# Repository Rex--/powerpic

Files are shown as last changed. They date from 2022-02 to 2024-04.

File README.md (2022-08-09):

# PowerPIC Calculator Watch
The PowerPIC is a replacement board for Casio CA-53W Databank watches with
upgraded hardware and customizable firmware. The project was designed with
the intent for a personal watch, but all of the needed design files and
firmware is available for free so anyone can make their own (if you can get
the PICs!).

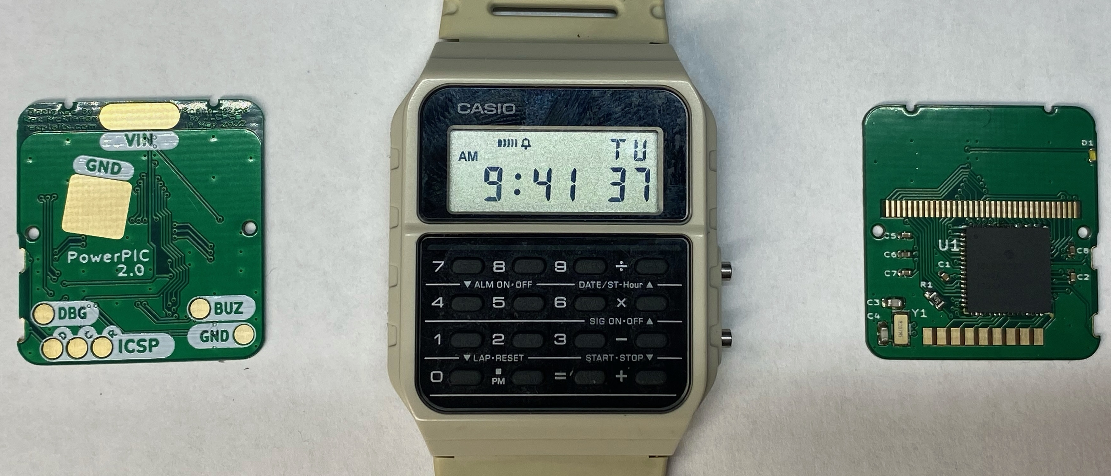
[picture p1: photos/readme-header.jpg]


## Features
- Full control of all 82 segments on the original display.
- Interrupt enabled keypad and buttons.
- Variable frequency piezo buzzer.
- Single color LED backlight.
- Built in temperature sensor.
- 12-bit ADC for sensing battery charge.

## Documentation
**Firmware:** The current state of the firmware is heavily evolving, so
the best source of documentation is the code itself, located in the `firmware/`
directory. A Doxyfile is provided, however the generated documentation should
be considered incorrect and outdated.

**Hardware:** Design files and schematics are available in the `hardware/`
directory.

## Credits
Thanks to Travis and Joey, I obtained a lot of inspiration from their projects:
- [GoodWatch](https://github.com/travisgoodspeed/goodwatch) --
Another CA-53W replacement board based on TI's MSP430.
- [Sensor Watch](https://github.com/joeycastillo/Sensor-Watch) --
A replacement board for the classic Casio F-91W based on Microchip's ATSAML22.

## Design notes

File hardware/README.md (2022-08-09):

# PowerPIC Hardware

The PowerPIC is built on a PIC16LF19197 with 56KB of flash memory and 4KB of RAM.
Required features included: a real time clock and calendar module for timekeeping,
a LCD controller for driving the stock Casio display, and a 10-bit PWM for driving
the piezo buzzer. Some additional useful features are: a 12-bit ADC for roughly
determining battery level, and a temperature sensor for roughly gauging temperature.

The only other components besides the required passives are a 32.768kHz crystal,
and a LED that is used for the backlight.

## Changelog

**Version 2.0**
- Added experimental backlight.
- Added RTC crystal for accurate timekeeping.

**Version 1.1**
- Switched buzzer from RF0 to RG7 so we can use the PWM peripheral.
- Switched keypad rows to RA0-RA3. Row 1 was using RA5 which is VBAT and unusable as digital output
- Added additional test points for the side buttons, allowing buttons to be simulated for development
- Added additional GND test point

**Version 1.0**
 - First hardware version

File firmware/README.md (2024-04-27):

# CasiOS
The watch firmware is written in C and compiled with Microchip's `xc8` compiler.
Functionality is separated into 'mode' applications, with each mode implementing
a set of procedures to be run when active. The active mode is changed by the Mode
side button, with each press cycling through an array of modes.

## Requirements
The following programs are required to build and flash the firmware:
- `make`
- `xc8` - Microchip's C compiler for PICx Devices
- `picchick` - Flash PICs using an AVR device. Get it 
[from the repo](https://github.com/rex--/picchick).

## Configuration

### Build Options
These options modify things about the firmware at build time and can be found
in the Makefile:
- `MODES` - A list of modes to compile into the firmware.
- `PCB_REV` - PCB Major version number. Changes some pins and which clock to use.
- `LOG_LVL` - Sets the amount of logged information. Logs above the specified
    level are not compiled into the final firmware, so expect things to run
    differently. A log level of '0' is recommend for builds that are going into a
    watch for use.
- `XTAL_FREQ` - The frequency in Hertz of the oscillator. Changing this value
    _DOES_ change the frequency of the internal oscillator!
- `BOOT_OFFSET` - Offset for bootloader. Set to 0 if not using a bootloader.

### Library Config
Some libraries have their own configuration options. These can be found in
the corresponding header files in `src/lib/`:
- **logging.h**
  - `LOGGING_UART_BAUDRATE` - The baud rate of the debug UART connection.

### Programmer Config
Configure the serial device to use in the Makefile. This should be a
1-wire capable serial converter.
- `PROGRAMMER_PORT` - Serial port of picchick compatible programmer. 
    e.g. _/dev/ttyUSB0_ or _COM3_
- `PROGRAMMER_BAUD` - Baud rate of programmer serial connection.
- `PROGRAMMER_FLAGS` - Additional programmer flags to use.

### Configuring Modes
To configre which modes are built into the firmware, edit the `modes.cfg`
file located in `src/modes/`. Each mode's source files, header files, and
mode_app_t struct should have the same name which corresponds to the name used
in the config file.

## Building
Compilation is achieved with the _make_ utility. A run of the `make fw` command
will produce a CasiOS.hex file in the sub-directory `build/`. The command
`make clean` will delete all built files, and a `make fclean` will remove all
files and created directories.
```sh
make [fw]       # Build firmware with settings defined in Makefile
make clean      # Remove built firmware files
make fclean     # Remove all created files and folders
```

The header file `src/modes/mode_config.h` is automatically generated with the
`make config` command. The generated files can be removed with `make cclean`.
Note that the config is generated automatically with `make fw` and removed with
a `make fclean`.
```sh
make config     # Generate config files
make cclean     # Remove generated files
```

## Upload
Python utility `picchick` is used by the Makefile in conjuction with
**flipflop** to upload firmware. It requires a serial device connected to
the PowerPIC's Debug and Ground pins. For further information about uploading
firmware checkout [flipflop](https://github.com/Rex--/flipflop), the bootloader
used for the PowerPIC.

After configuring the serial device in the Makefile, `make upload` should
upload the firmware to the watch. Don't forget to enter the bootloader by
resetting the watch!

```sh
make upload      # Upload firmware using picchick
```

## Copying
Copyright © 2022-2024 Rex McKinnon \
This software is released under the University of Illinois/NCSA Open Source
License. Check the LICENSE file for more details.

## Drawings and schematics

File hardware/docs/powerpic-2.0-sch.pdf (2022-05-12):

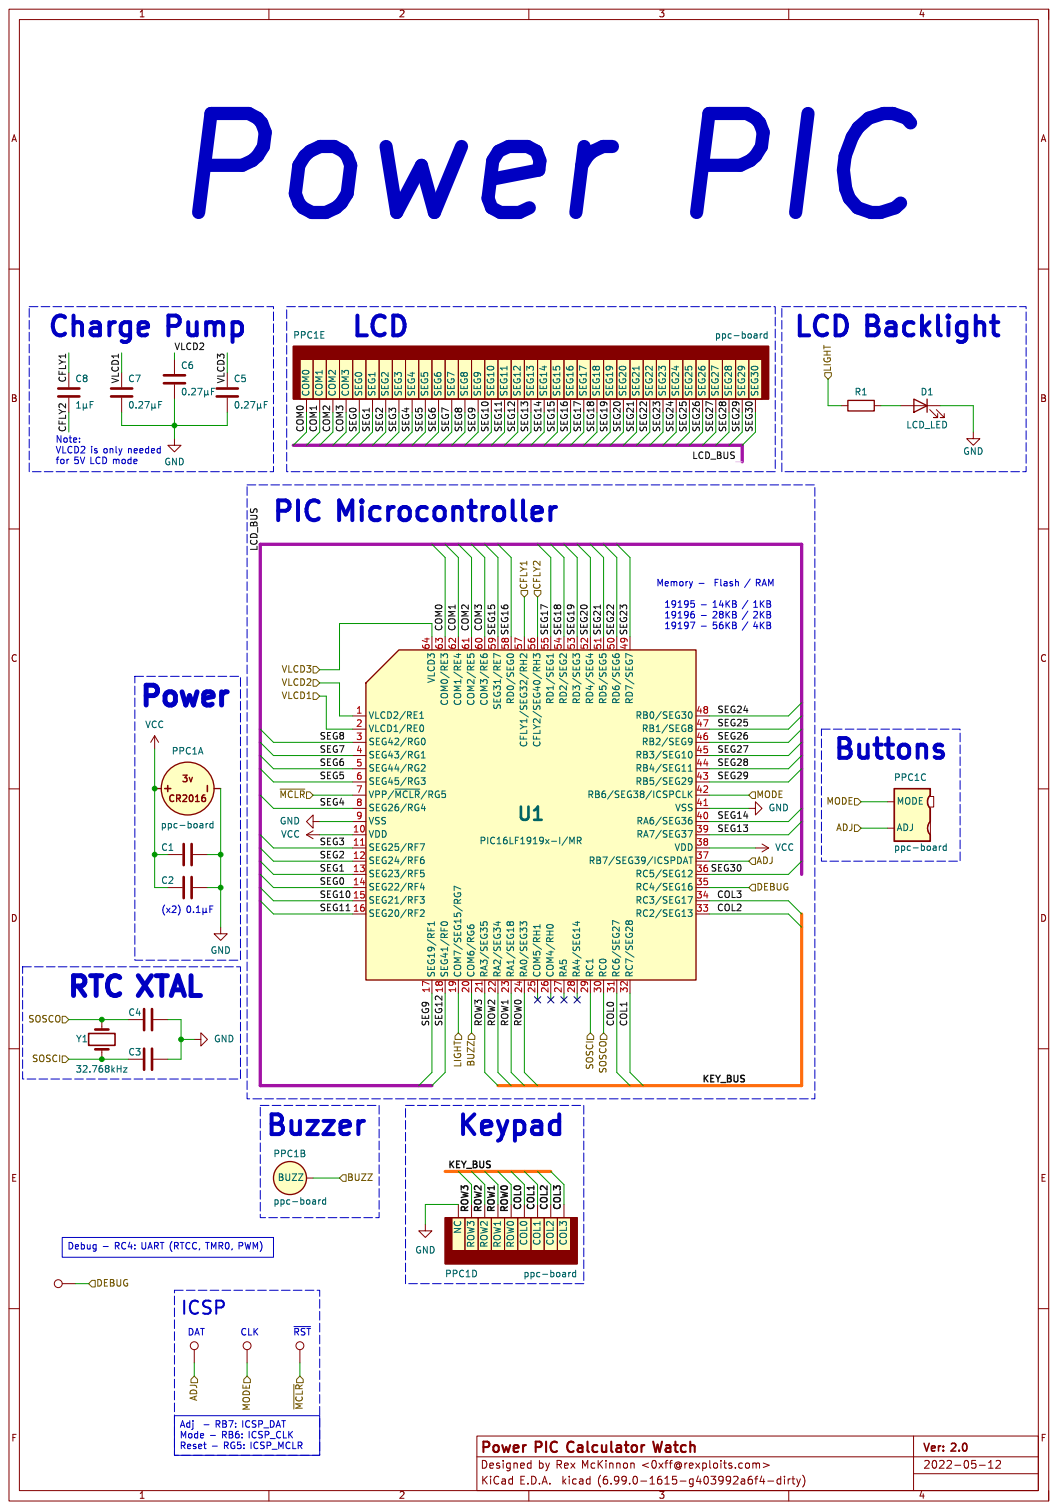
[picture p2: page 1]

for 5V LCD mode Charge Pump

Note: VLCD2 is only needed

Debug - RC4: UART (RTCC, TMR0, PWM)

2022-05-12 Power PIC Calculator Watch

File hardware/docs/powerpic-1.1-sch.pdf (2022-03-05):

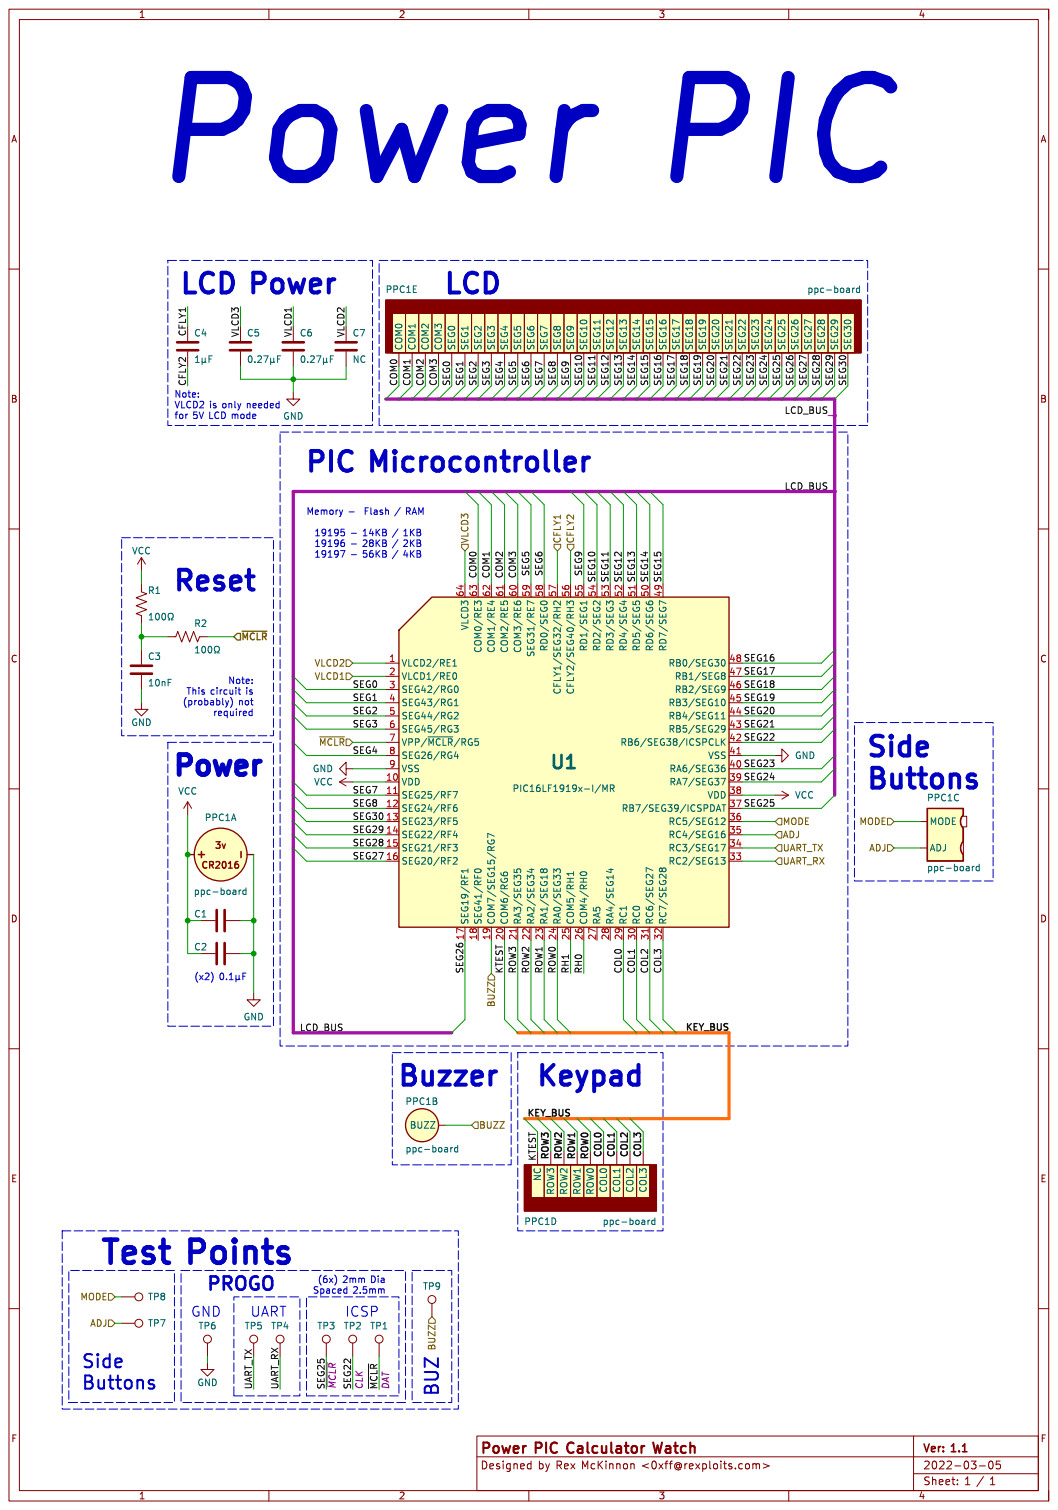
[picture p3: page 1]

Note: VLCD2 is only needed

Note: This circuit is

2022-03-05 Sheet: 1 / 1 Power PIC Calculator Watch
Designed by Rex McKinnon <0xff@rexploits.com>

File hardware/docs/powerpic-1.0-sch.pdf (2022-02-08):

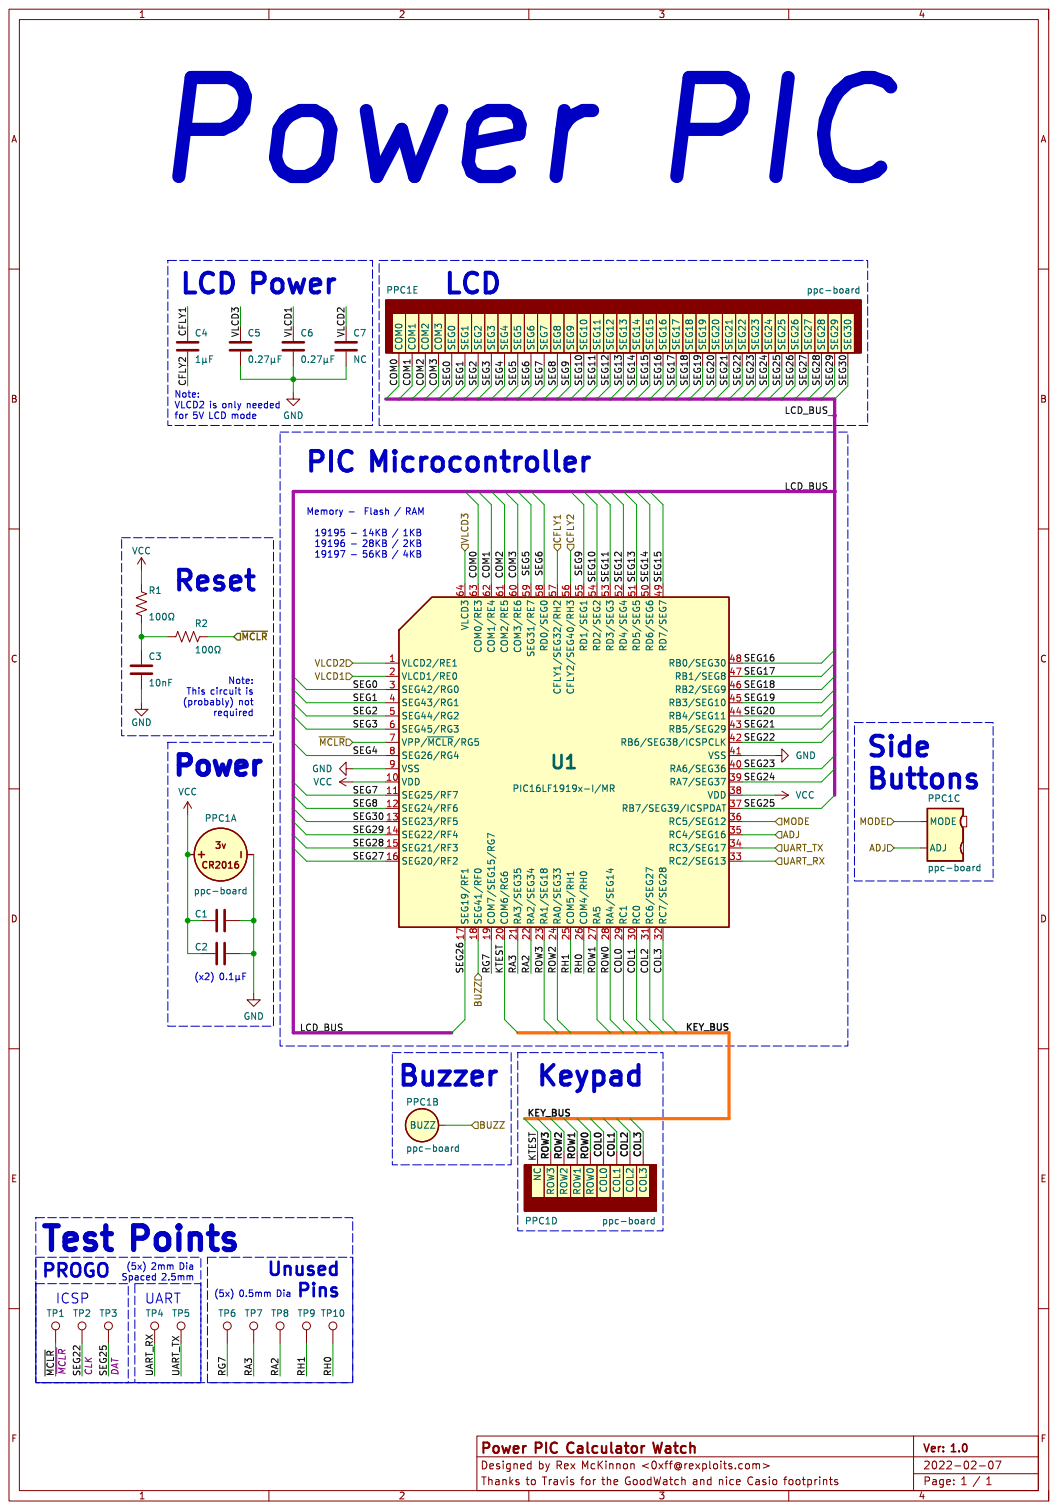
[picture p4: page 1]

for 5V LCD mode LCD Power

Note: VLCD2 is only needed

Note: This circuit is

Power PIC Calculator Watch
Designed by Rex McKinnon <0xff@rexploits.com>

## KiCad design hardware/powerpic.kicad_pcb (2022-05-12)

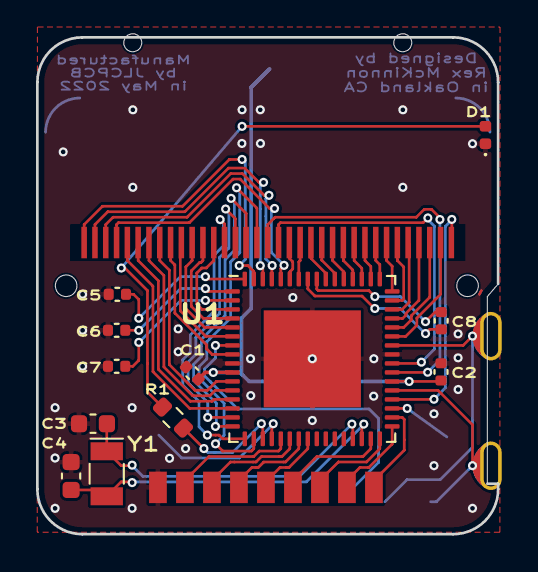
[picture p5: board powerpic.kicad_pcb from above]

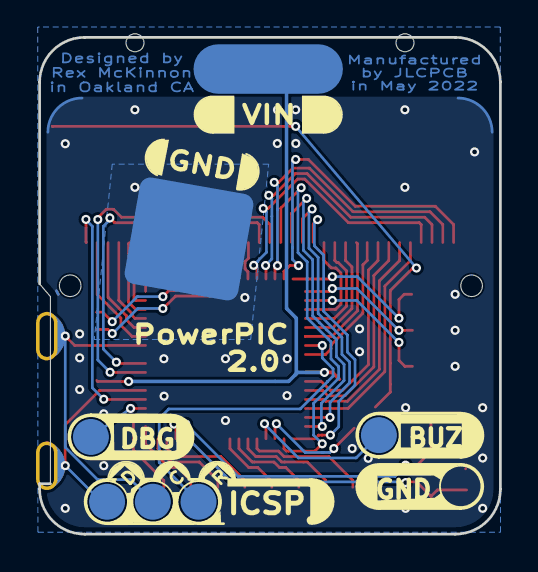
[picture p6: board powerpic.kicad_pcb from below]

Board: 2 copper layers, 25.6 x 27.6 mm, 17 parts (4 on the bottom side), 59 nets.

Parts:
C1, C2: 0.1μF; C_0402_1005Metric
C3, C4: TBD; C_0603_1608Metric
C5, C6, C7: 0.27μF; C_0402_1005Metric
C8: 1μF; C_0402_1005Metric
D1: LCD_LED; LED_0402_1005Metric
PPC1: ppc-board
R1: TBD; R_0603_1608Metric
TP1: ~{MCLR}; Progo_Pad_D2.0mm
TP2: Mode; Progo_Pad_D2.0mm
TP3: Adj; Progo_Pad_D2.0mm
TP4: Debug; Progo_Pad_D2.0mm
U1: PIC16LF1919x-I/MR; QFN-64-1EP_9x9mm_P0.5mm_EP5.4x5.4mm
Y1: 32.768kHz; Crystal_SMD_MicroCrystal_CC7V-T1A-2Pin_3.2x1.5mm

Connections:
/ADJ: PPC1.5 (ADJ), TP3.1, U1.37 (RB7/SEG39/ICSPDAT)
/BUZZ: PPC1.3 (BUZZ), U1.20 (COM6/RG6)
/CFLY1: C8.1, U1.57 (CFLY1/SEG32/RH2)
/CFLY2: C8.2, U1.56 (CFLY2/SEG40/RH3)
/COL0: PPC1.11 (COL0), U1.31 (RC6/SEG27)
/COL1: PPC1.12 (COL1), U1.32 (RC7/SEG28)
/COL2: PPC1.13 (COL2), U1.33 (RC2/SEG13)
/COL3: PPC1.14 (COL3), U1.34 (RC3/SEG17)
/COM0: PPC1.15 (COM0), U1.63 (COM0/RE3)
/COM1: PPC1.16 (COM1), U1.62 (COM1/RE4)
/COM2: PPC1.17 (COM2), U1.61 (COM2/RE5)
/COM3: PPC1.18 (COM3), U1.60 (COM3/RE6)
/DEBUG: TP4.1, U1.35 (RC4/SEG16)
/LIGHT: R1.2, U1.19 (COM7/SEG15/RG7)
/MODE: PPC1.4 (MODE), TP2.1, U1.42 (RB6/SEG38/ICSPCLK)
/ROW0: PPC1.10 (ROW0), U1.24 (RA0/SEG33)
/ROW1: PPC1.9 (ROW1), U1.23 (RA1/SEG18)
/ROW2: PPC1.8 (ROW2), U1.22 (RA2/SEG34)
/ROW3: PPC1.7 (ROW3), U1.21 (RA3/SEG35)
/SEG0: PPC1.19 (SEG0), U1.14 (SEG22/RF4)
/SEG1: PPC1.20 (SEG1), U1.13 (SEG23/RF5)
/SEG2: PPC1.21 (SEG2), U1.12 (SEG24/RF6)
/SEG3: PPC1.22 (SEG3), U1.11 (SEG25/RF7)
/SEG4: PPC1.23 (SEG4), U1.8 (SEG26/RG4)
/SEG5: PPC1.24 (SEG5), U1.6 (SEG45/RG3)
/SEG6: PPC1.25 (SEG6), U1.5 (SEG44/RG2)
/SEG7: PPC1.26 (SEG7), U1.4 (SEG43/RG1)
/SEG8: PPC1.27 (SEG8), U1.3 (SEG42/RG0)
/SEG9: PPC1.28 (SEG9), U1.17 (SEG19/RF1)
/SEG10: PPC1.29 (SEG10), U1.15 (SEG21/RF3)
/SEG11: PPC1.30 (SEG11), U1.16 (SEG20/RF2)
/SEG12: PPC1.31 (SEG12), U1.18 (SEG41/RF0)
/SEG13: PPC1.32 (SEG13), U1.39 (RA7/SEG37)
/SEG14: PPC1.33 (SEG14), U1.40 (RA6/SEG36)
/SEG15: PPC1.34 (SEG15), U1.59 (SEG31/RE7)
/SEG16: PPC1.35 (SEG16), U1.58 (RD0/SEG0)
/SEG17: PPC1.36 (SEG17), U1.55 (RD1/SEG1)
/SEG18: PPC1.37 (SEG18), U1.54 (RD2/SEG2)
/SEG19: PPC1.38 (SEG19), U1.53 (RD3/SEG3)
/SEG20: PPC1.39 (SEG20), U1.52 (RD4/SEG4)
/SEG21: PPC1.40 (SEG21), U1.51 (RD5/SEG5)
/SEG22: PPC1.41 (SEG22), U1.50 (RD6/SEG6)
/SEG23: PPC1.42 (SEG23), U1.49 (RD7/SEG7)
/SEG24: PPC1.43 (SEG24), U1.48 (RB0/SEG30)
/SEG25: PPC1.44 (SEG25), U1.47 (RB1/SEG8)
/SEG26: PPC1.45 (SEG26), U1.46 (RB2/SEG9)
/SEG27: PPC1.46 (SEG27), U1.45 (RB3/SEG10)
/SEG28: PPC1.47 (SEG28), U1.44 (RB4/SEG11)
/SEG29: PPC1.48 (SEG29), U1.43 (RB5/SEG29)
/SEG30: PPC1.49 (SEG30), U1.36 (RC5/SEG12)
/SOSCI: C3.1, U1.29 (RC1), Y1.1
/SOSCO: C4.1, U1.30 (RC0), Y1.2
/VLCD1: C7.1, U1.2 (VLCD1/RE0)
/VLCD2: C6.1, U1.1 (VLCD2/RE1)
/VLCD3: C5.1, U1.64 (VLCD3)
/~MCLR: TP1.1, U1.7 (VPP/~MCLR/RG5)
GND: C1.1, C2.1, C3.2, C4.2, C5.2, C6.2, C7.2, D1.1 (K), PPC1.2 (GND), PPC1.6 (NC), U1.9 (VSS), U1.41 (VSS), U1.65 (VSS)
unnamed: D1.2 (A), R1.1
VCC: C1.2, C2.2, PPC1.1 (VCC), U1.10 (VDD), U1.38 (VDD)

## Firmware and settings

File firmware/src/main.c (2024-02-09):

/** @file main.c
 *
 * Main program for the PowerPIC firmware.
 *
 * TODO: Write a nice description about the PowerPIC firmware.
 * 
*/

#include <xc.h>

#include "post.h"

#include "lib/system.h"
#include "lib/isr.h"
#include "lib/mode.h"
#include "lib/events.h"
#include "lib/tick.h"
#include "lib/datetime.h"
#include "lib/alarm.h"
#include "lib/buttons.h"
#include "lib/keypad.h"
#include "lib/backlight.h"
#include "lib/buzzer.h"
#include "lib/display.h"
#include "lib/battery.h"

#define LOG_TAG "main"
#include "lib/logging.h"


/**
 * Setup of hardware and libs on POR.
 * This function gets called exactly once at every reset event.
*/
void
setup (void)
{
    // Initialize the base system.
    // - Oscillator (xtal)
    // - Default pin states (pins)
    //
    system_init();

    // Init logging lib so it is available for use by libs.
    logging_init();

    // Initialize peripheral libraries:
    // - Timers     (tick.h)
    // - RTCC       (datetime.h)
    //   - Alarm    (alarm.h)
    // - LCD        (display.h)
    // - Keypad     (keypad.h)
    // - Buttons    (buttons.h)
    // - Buzzer     (buzzer.h)
    // - Backlight  (backlight.h)
    // - ADC        (battery.h)
    //
    tick_init();
    datetime_init();
    alarm_init();
    display_init();
    keypad_init();
    buttons_init();
    buzzer_init();
    backlight_init();
    battery_init();
}

/**
 * Entrypoint of firmware.
 * This contains the main loop.
*/
void
main (void)
{
    setup();

    post_bios();

    // Initialize our modes. This calls each mode's init() function. It then
    // starts the default mode (whatever is at mode_list index 0) and configures
    // the system according to the mode's config.
    mode_init();

    // Update display in case started mode drew something
    display_update();

    // Tickrate was configured above, so we can enable ticks.
    // This could be moved to the init() call above.
    tick_enable();

    LOG_INFO("Starting main loop...");
    for( ;; )
    {
        if (event_check())
        {
            // If we have an event in the queue, we call the mode thread to
            // handle it.
            mode_thread();
            
            // Update the display after running the mode.
            display_update();
        }

        // If logs are not disabled, wait for the transmit buffer to empty
        // before going to sleep.
#       if LOG_LVL
        while (!logging_buffer_empty() || !TX1STAbits.TRMT)
        {
            // Wait for transmit buffer to empty
        }
#       endif

        // Go to sleep. An interrupt will wake us up when something happens.
        SLEEP();

        // The instruction after sleep is always executed first when waking up.
        // This NOP makes sure we don't do anything weird.
        NOP();
    }
}


// EOF //

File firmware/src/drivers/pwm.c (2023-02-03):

/** @file pwm.h
 * 
 * PWM driver for PIC16LF1919x.
*/

#include <xc.h>
#include <math.h>   // for llroundf()

#include "drivers/timers.h"

#include "drivers/pwm.h"


/** Currently cofigured duty cycle. */
unsigned char pwm_duty_ratio = 0;

/** Currently configured frequency. */
unsigned int pwm_frequency = 0;

/** Calculated timer period for the given frequency. */
volatile unsigned char pwm_timer_period = 0;

/** Calculated timer prescale value for the given frequency. */
volatile unsigned char pwm_timer_prescaler = 0;

/** Calculated duty-cycle value. */
volatile unsigned int pwm_duty_cycle = 0;

void
pwm_init (void)
{
#   if (1 == PCB_REV)
    // Set pwm pin to output and configure pps
    TRISGbits.TRISG7 = 0;
    RG7PPS = 0x0c;

#   else
    // Set PWM pin as output
    // We use RG6 for the buzzer
    //
    TRISGbits.TRISG6 = 0;
    RG6PPS = 0x0C;
#   endif

    // Init up timer4
    //
    timer4_init();

    // Configure PWM4 to use timer4
    CCPTMRS0bits.P4TSEL = 0b10;
}

void
pwm_enable (void)
{
    // Enable timer
    timer4_start(); 

    // Enable PWM
    PWM4CONbits.PWM4EN = 1;
}

void
pwm_disable (void)
{
    // Disable pwm
    PWM4CONbits.PWM4EN = 0;

    // Disable timer
    timer4_stop();
}

void
pwm_freq_set (unsigned int freq)
{
    // To set the PWM to a given frequency we need to figure out two things:
    // 1. Timer period
    // 2. Timer prescaler
    //
    // To calculate the correct values, we start with the lowest available
    // prescaler (1:1). We then calculate the timer period value for each value
    // and stop at the first that is within the timer limits. This gives us the
    // prescale option with the highest resolution available for the frequency.

    int timer_period = 0;
    // As prescaler values get lower, it allows higher frequencies.
    //
    for (unsigned char timer_prescale = 0; timer_prescale < 8; timer_prescale++)
    {
        // Magic formula from the datasheet gives us our timer period.
        // This takes up about 7% of our flash because of the float arithmetic.
        //
        timer_period = (int)lroundf(
            (1 / ((float)freq) /
            (4 * (1 / (float)_XTAL_FREQ) * (1 << timer_prescale))) - 1
        );

        if ((0 < timer_period) && (timer_period < 255))
        {
            pwm_frequency = freq;

            pwm_timer_period = (unsigned char)timer_period;
            timer4_period_set(pwm_timer_period); // TODO: Don't actually set the period registers until we enable.
            pwm_timer_prescaler = timer_prescale;
            timer4_prescaler_set(pwm_timer_prescaler); // TODO: Same with prescaler
            return;
        }
    }
    // Error: bad frequency!
    // What can we do? Should this function return something?
    // Set some defaults?
}

unsigned int
pwm_freq_get (void)
{
    return pwm_frequency;
}


void
pwm_duty_set (unsigned char duty)
{
    pwm_duty_ratio = duty; // LOL -- DUTY!
    pwm_duty_cycle = (unsigned int)lroundf(((float)duty/100) * (4 * (pwm_timer_period + 1)));

    PWM4DC = (pwm_duty_cycle << 6);
}

unsigned char
pwm_duty_get (void)
{
    return pwm_duty_ratio;
}


// EOF //

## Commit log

2022-02-08 Added powerpic schematic
    [powerpic.kicad_sch]
2022-02-10 Added PCB design files
    [powerpic.kicad_pcb]
2022-02-10 Added some silkscreen labels, and noticed a design error. Final commit before version bump
    [powerpic.kicad_pcb]
2022-03-05 Version 1.0 of pcb
    [powerpic.kicad_pcb]
2022-03-05 Version 1.1 Release
    [powerpic.kicad_pcb, powerpic.kicad_sch]
2022-03-05 Changed directory naming scheme
    [powerpic.kicad_pcb, powerpic.kicad_sch]
2022-03-11 Basic firmware layout, included UART driver as example.
2022-05-12 Redesigned board with RTCXTAL and led backlight
    [powerpic.kicad_pcb, powerpic.kicad_sch]
2022-05-21 Added support for v2 boards. Lots of various other changes
2022-05-23 Changed clock speed to 32MHz from 1MHz. Split EUSART configuration for UART into a driver.
2022-06-23 Display driver now less aggressive about positions when displaying numbers.
2022-06-23 Mode's run function now returns value signalling to switch modes.
2022-06-29 Fixed tick lib to generate an event at the requested rate. Previously, every event was resetting the tick timer.
2022-07-25 clock_mode: - Added date display with '/' (divide) key. - Date is now settable by the user in the ADJ button menu.
2022-08-07 buzzer lib: Work on changing buzzer timer to be interrupt-based.
    [pwm.c]
2022-08-07 pwm driver: Fixed a mismatched return type. backlight lib: Fixed a bug with toggling the backlight. test mode: Started working towards a 'POST' mode that verifies watch functionality.
2022-08-08 Added new POST procedure to run after reset.
    [main.c]
2022-08-09 Added legacy v1.0 schematic.
2022-08-13 battery lib: Now enabling ADC only when sampling.
2022-08-13 power mode: Added new mode that displays battery voltage.
2022-08-14 clock, alarmclock, power modes: Better interfaces.
2022-08-19 temperature mode: Calculate temperature based on internal sensor.
2022-08-19 thermometer mode: Basic mode that displays the temperature. The temperature lib it's based on uses the internal temp sensor so it is labeled CPU to indicate it's probably not ambient temp.
2022-08-20 settings lib: Basic data storage lib. Uses device EEPROM.
2022-08-26 Switched firmware to use flipflop bootloader.
2022-10-15 clock mode: Added backlight button to clock face.
2022-10-15 thermometer mode: Added calibrate functionality. temperature lib: Added calibrate procedure that records the current adc reading. nvm driver: Added procedure to read from all PFM locations.
2022-10-31 buzzer lib: Added ability to play RTTTL ringtones. Currently these ringtones are stored as strings in RTTTL format.
    [pwm.c]
2023-01-28 buttons lib: Added some basic debouncing using timer1.
2023-02-03 pwm driver: switch PWM4 to TMR4. The PWM4 peripheral used for buzzer now uses Timer4 instead of Timer2.
    [pwm.c]
2023-02-04 stopwatch mode: Work towards adding a stopwatch mode that implements various timers.
2023-02-04 Added super basic timer mode, only countdown is implemented
2023-04-07 Added basic debug display. The primary display is printed out as ascii characters. Currently only enabled on INFO and higher log levels.
2023-12-10 Small changes to compile with version 2.45 of xc8: - putch function changed to take just "char" as argument. - Configuration bit for PowerUp Timer selection changed from PWRTE to PWRTS.
2023-12-10 Fixed warnings in timer.c
2023-12-14 Modified clock mode to hopefully be more efficient: - EEPROM setting get loaded on every start of the mode, instead of once at init. - Changed method of updating the seconds by incrementing and synci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
2024-02-09 device_config: flipflop bootloader now uses CONFIG3 - WDT.
2024-02-09 rtcc driver: added chip specific logic to driver
2024-02-09 datetime lib: updated to use new rtcc driver
2024-02-09 timer mode: fixed bugs in countdown timer, added mario chime
2024-04-27 makefile: build firmware based on list of modes
    [modes.cfg]
